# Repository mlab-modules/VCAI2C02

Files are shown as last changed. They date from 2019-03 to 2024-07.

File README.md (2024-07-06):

# VCAI2C02A

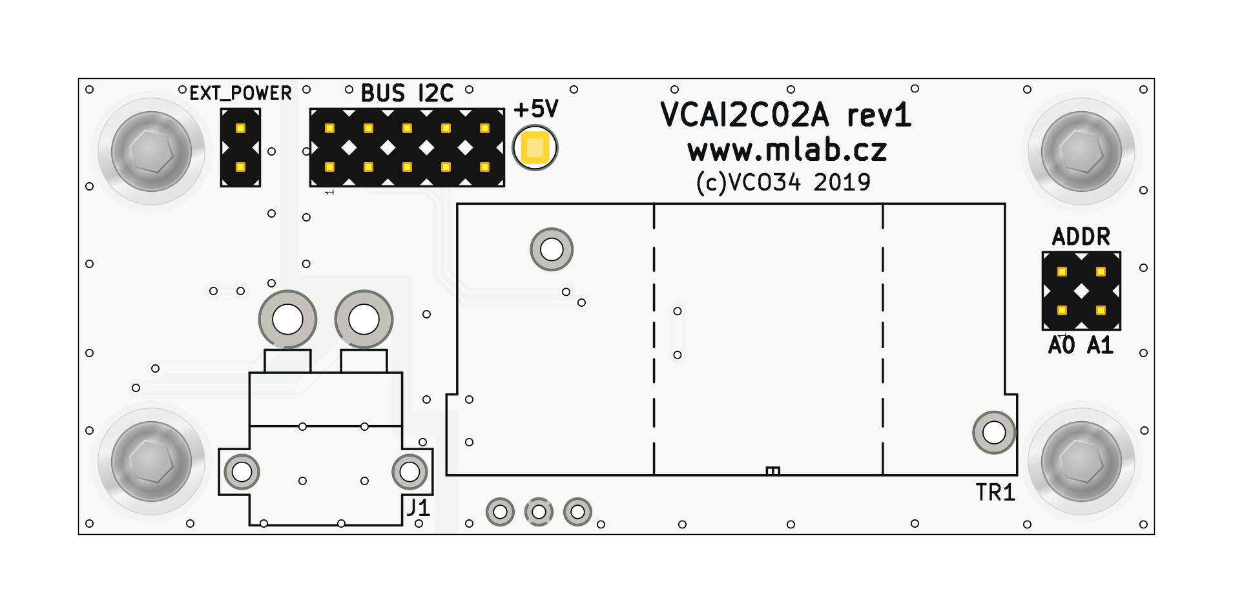
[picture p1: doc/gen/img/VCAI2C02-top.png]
VCAI2C02A

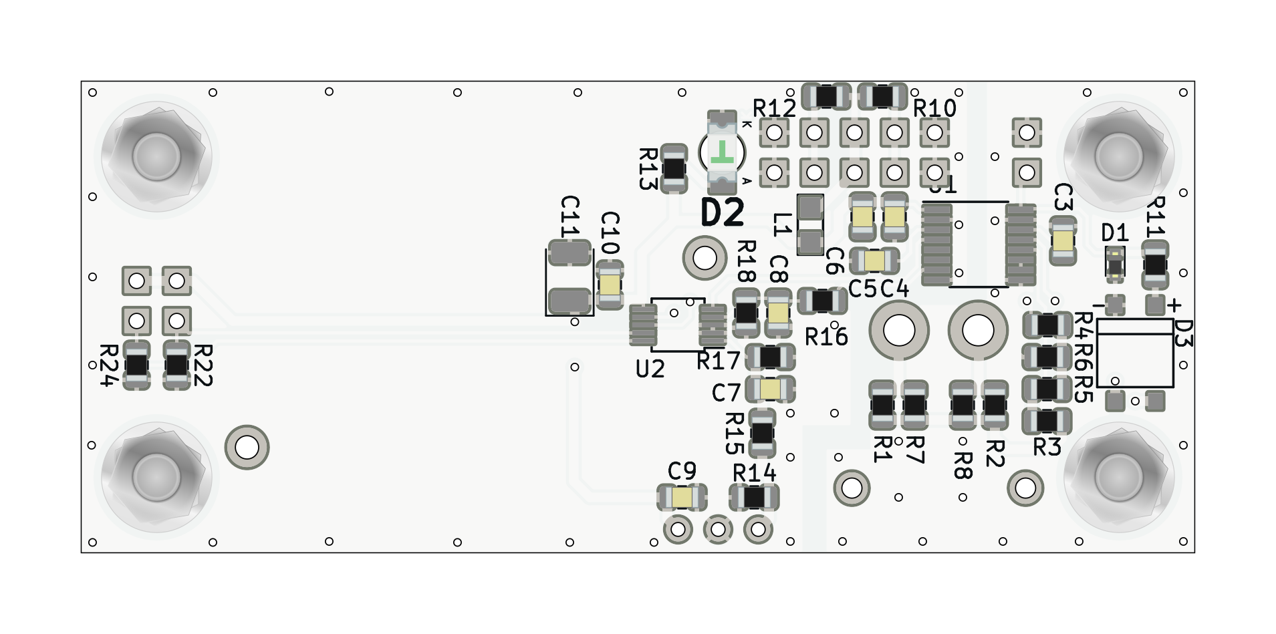
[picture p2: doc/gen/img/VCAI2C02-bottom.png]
VCAI2C02A bottom


## Overview

The VCAI2C02A is an I2C module designed for measuring current (0-50A) and voltage (0-50V) using a measuring transformer. It integrates multiple components to provide accurate and reliable measurements for various applications.

## Features

- **Current Measurement:** 0 to 50A
- **Voltage Measurement:** 0 to 50V
- **Interface:** I2C
- **Measurement Transformer:** Included
- **Connectors:** XT30PW-M and XT30PW-F
- **High Stability Isolated Error Amplifier:** ADuM3190
- **High-Resolution ADC:** MCP3423

## Components

### XT30PW Connectors

- **Item No:** XT30PW-M and XT30PW-F
- **Contact Resistance:** 0.80mΩ
- **Rated Voltage:** DC 500V
- **Rated Current:** 15A
- **Instantaneous Current:** 30A
- **Material:** Brass Gold Plated
- **Insulation Material:** PA, UL94 V0
- **Operating Temperature:** -20℃ to 120℃

### ADuM3190 Isolated Error Amplifier

- **Stability in isolated feedback applications**
- **Initial Accuracy:** 0.5%
- **Accuracy over Temperature Range:** 1%
- **Reference Voltage:** 1.225V
- **Bandwidth:** 400 kHz
- **Isolation Voltage:** 2.5 kV rms
- **Temperature Range:** -40°C to +125°C

### MCP3423 ADC

- **Resolution:** 18-bit
- **Interface:** I2C
- **Programmable Data Rate**
- **Internal Voltage Reference:** 2.048V

### Hall Effect Current Sensor (Tamura L01ZXXXS05 Series)

- **Type:** Open Loop
- **Mounting:** PCB
- **Nominal Current:** Up to 600A
- **Accuracy:** Excellent accuracy and linearity
- **Temperature Drift:** Low
- **Frequency Bandwidth:** Wide
- **No Insertion Loss**

## Applications

- **Linear Power Supplies**
- **Inverters**
- **Uninterruptible Power Supply (UPS)**
- **DOSA-compatible Modules**
- **Voltage Monitors**
- **Automotive and drone Systems**

## Additional Resources

For more detailed information, please refer to the datasheets of the components used in the VCAI2C02A module:

- [ADuM3190 Datasheet](https://www.analog.com/media/en/technical-documentation/data-sheets/ADuM3190.pdf)
- [MCP3423 Datasheet](https://www.microchip.com/wwwproducts/en/MCP3423)
- [XT30PW Connectors Specification](http://www.china-amass.com/)

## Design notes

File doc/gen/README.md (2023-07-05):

# PCB

Board size: 70.61x29.97 mm (2.78x1.18 inches)

- This is the size of the rectangle that contains the board
- Thickness: 1.6 mm (63 mils)
- Material: FR4
- Finish: HAL
- Layers: 2
- Copper thickness: 35 µm

Solder mask: TOP / BOTTOM

- Color: Green

Silk screen: TOP / BOTTOM

- Color: White

# Important sizes

Clearance: 0.2 mm (8 mils)

Track width: 0.2 mm (8 mils)

- By design rules: 0.2 mm (8 mils)

Drill: 0.5 mm (20 mils)

- Vias: 0.5 mm (20 mils) [Design: 0.3 mm (12 mils)]
- Pads: 0.9 mm (35 mils)
- The above values are real drill sizes, they add 0.1 mm (4 mils) to plated holes (PTH)

Via: 0.8/0.4 mm (31/16 mils)

- By design rules: 0.8/0.2 mm (31/8 mils)
- Micro via: yes [0.2/0.1 mm (8/4 mils)]
- Buried/blind via: yes
- Total: 54 (thru: 54 buried/blind: 0 micro: 0)

Outer Annular Ring: 0.15 mm (6 mils)

- By design rules: 0.26 mm (10 mils)

Eurocircuits class: 4B
- Using min drill 0.5 mm for an OAR of 0.15 mm

# General stats

Components count: (SMD/THT)

- Top: 0/9 (THT)
- Bottom: 32/2 (SMD + THT)

Defined tracks:

- 0.2 mm (8 mils)
- 0.4 mm (16 mils)
- 0.6 mm (24 mils)
- 0.8 mm (31 mils)
- 1.0 mm (39 mils)

Used tracks:

- 0.2 mm (8 mils) (187) defined: yes
- 0.4 mm (16 mils) (15) defined: yes
- 0.6 mm (24 mils) (70) defined: yes

Defined vias:

Used vias:

- 0.8/0.4 mm (31/16 mils) (Count: 54, Aspect: 2.0 A) defined: no

Holes (excluding vias):

- 0.8 mm (31 mils) (3)
- 0.89 mm (35 mils) (16)
- 1.2 mm (47 mils) (2)
- 1.4 mm (55 mils) (2)
- 1.9 mm (75 mils) (2)
- 2.7 mm (106 mils) (1)
- 3.0 mm (118 mils) (4)

Oval holes:

Drill tools (including vias and computing adjusts and rounding):

- 0.5 mm (20 mils) (54)
- 0.9 mm (35 mils) (3)
- 1.0 mm (39 mils) (16)
- 1.3 mm (51 mils) (2)
- 1.5 mm (59 mils) (2)
- 2.0 mm (79 mils) (2)
- 2.7 mm (106 mils) (1)
- 3.1 mm (122 mils) (4)

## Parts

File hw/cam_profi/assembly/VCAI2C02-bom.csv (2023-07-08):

Component | Description | Part | References | Value | Footprint | Quantity Per PCB | Datasheet | ust_id | mfpn
1 |  | C-Device | C7C8 | 10n | C_0805_2012Metric | 2 |  | 5c70984712875079b91f8b49
2 |  | C-Device | C4C9C10 | 100n | C_0805_2012Metric | 3 |  | 5c70984712875079b91f8b4c
3 |  | C-Device | C3C5C6 | 1u | C_0805_2012Metric | 3 |  | 5c70984812875079b91f8bc2
4 |  | C-Device | C11 | 10uF | CP_EIA-3528-21_Kemet-B | 1 |  | 5c70984412875079b91f8865
5 |  | LED-Device | D2 | +5V -Green | LED_1206 | 1 |  | 5c70984412875079b91f8895
6 |  | D_Bridge_+-AA-Device | D3 | CDBHM260L-HF | MSB-2 | 1 |  | 5cb5829a1287500e61c99661
7 |  | D_Zener-Device | D1 | MM5Z10VT1G | D_SOD-523 | 1 |  | 5cb5832e1287500e61c99679
8 |  | Conn_02x02_Odd_Even-Connector_Generic | J6 | ADDR | Straight_2x02 | 1
9 |  | Conn_02x05_Odd_Even-Connector_Generic | J4 | BUS I2C | Straight_2x05 | 1
10 |  | Conn_01x02-Connector_Generic | J5 | EXT_POWER | Straight_2x01 | 1
11 |  | Conn_01x02-Connector_Generic | J1 | IN 50V(max) | XT30PW-M | 1 |  | 5c70984812875079b91f8ba8
12 |  | L-Device | L1 | BLM21PG300SN1D | BLM21PG_3Amp | 1 |  | 5c70984412875079b91f87fd
13 |  | R-Device | R13 | 330R | R_0805_2012Metric | 1 |  | 5c70984512875079b91f8984
14 |  | R-Device | R5 | 1k5 | R_0805_2012Metric | 1 |  | 5c70984512875079b91f898e
15 |  | R-Device | R11 | 3k9 | R_0805_2012Metric | 1 |  | 5c70984612875079b91f8994
16 |  | R-Device | R10R12R14R22R24 | 10k | R_0805_2012Metric | 5 |  | 5c70984612875079b91f899f
17 |  | R-Device | R6 | 16k9 | R_0805_2012Metric | 1 |  | 5cb83a291287500e61c99759
18 |  | R-Device | R17R18 | 33k | R_0805_2012Metric | 2 |  | 5c70984712875079b91f8a8a
19 |  | R-Device | R4 | 40k2 | R_0805_2012Metric | 1 |  | 5cb839571287500e61c9974a
20 |  | R-Device | R3 | 50k | R_0805_2012Metric | 1 |  | 5cb585391287500e61c9968c
21 |  | R-Device | R15R16 | 180k | R_0805_2012Metric | 2 |  | 5c70984712875079b91f8a9c
22 |  | R-Device | R1R2R7R8 | 1M | R_0805_2012Metric | 4 |  | 5c70984712875079b91f8aaa
23 |  | L01ZxxxS05 | TR1 | L01ZxxxS05 | L01ZxxxS05 | 1 |  | 5cb581511287500e61c99631 | L01Z100S05
24 |  | ADuM3190 | U1 | ADuM3190ARQZ | QSOP-16_3.9x4.9mm_P0.635mm | 1 |  | 5cb589091287500e61c996a0 | ADuM3190ARQZ
25 |  | MCP3423-Analog_ADC | U2 | MCP3423-E/UN | MSOP-10_3x3mm_P0.5mm | 1 | http://ww1.microchip.com/downloads/en/DeviceDoc/22088c.pdf | 5cb589b51287500e61c996bf | MCP3423-E/UN

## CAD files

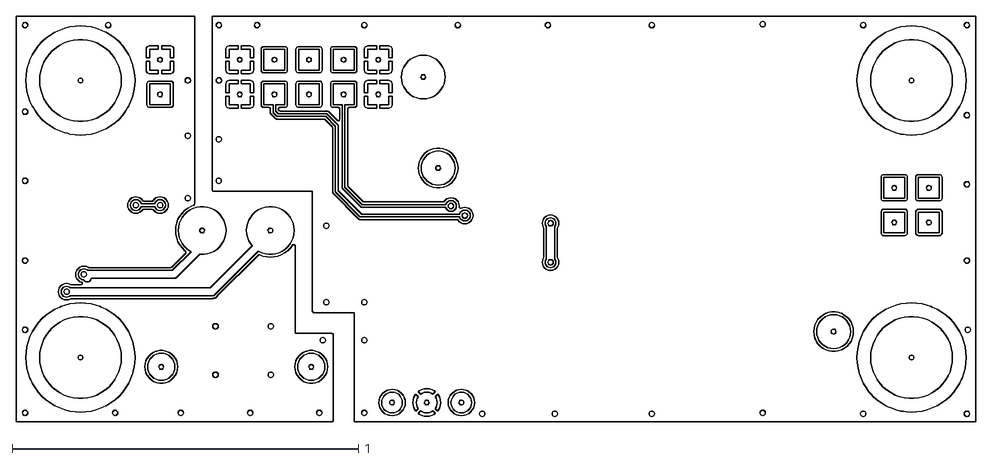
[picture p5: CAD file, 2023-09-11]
doc/gen/dxf/VCAI2C02-F_Cu.dxf
2.77 x 1.17

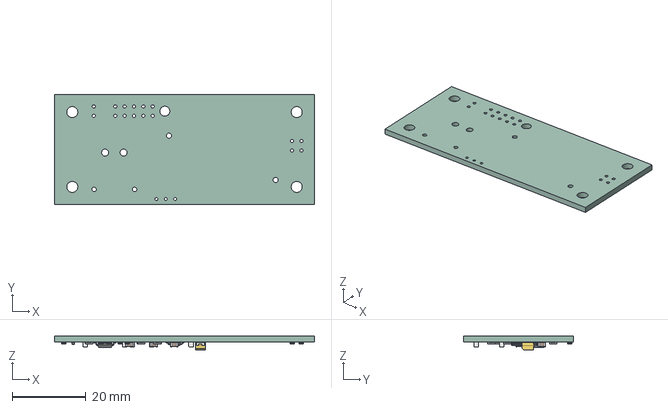
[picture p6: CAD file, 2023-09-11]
doc/gen/VCAI2C02.step
70.6 x 30.0 x 3.75 mm
tmpodnhxvpo PCB

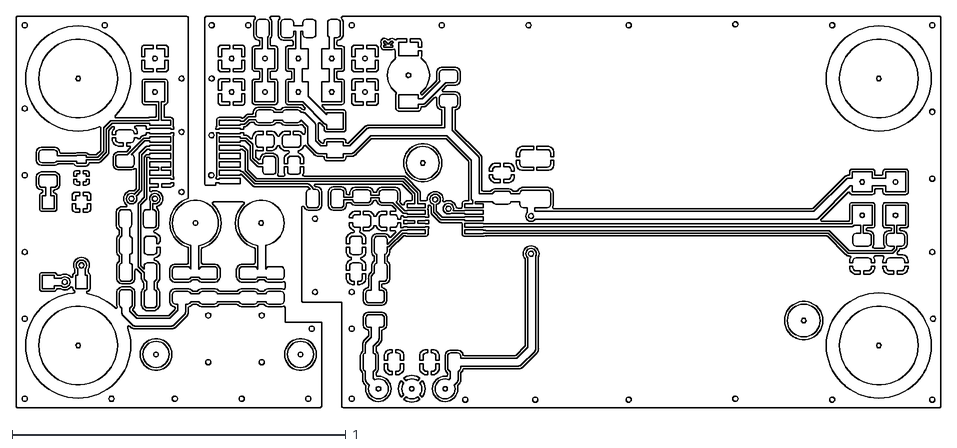
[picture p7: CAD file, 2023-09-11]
doc/gen/dxf/VCAI2C02-B_Cu.dxf
2.77 x 1.17

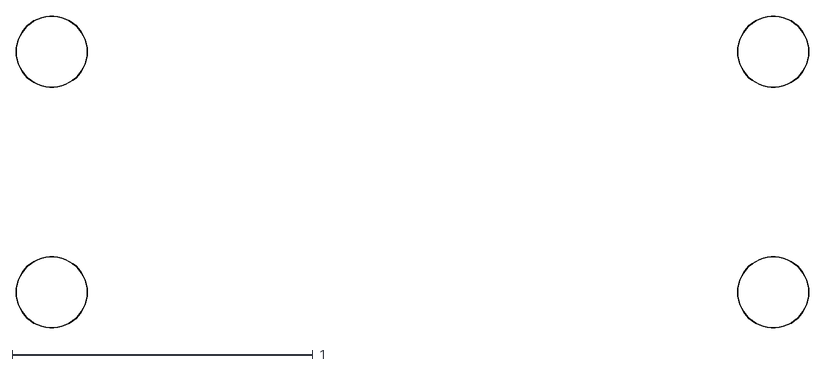
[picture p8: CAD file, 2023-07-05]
doc/gen/dxf/VCAI2C02-B_Adhesive.dxf
2.64 x 1.04

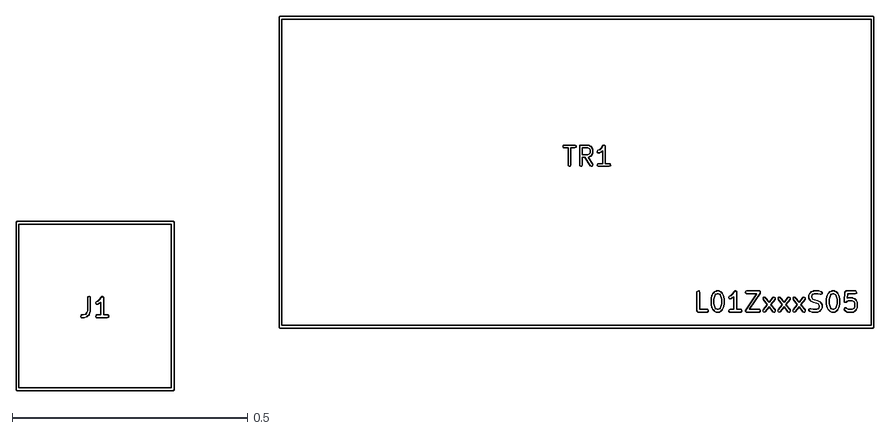
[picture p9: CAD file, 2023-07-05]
doc/gen/dxf/VCAI2C02-F_Fab.dxf
1.83 x 0.796

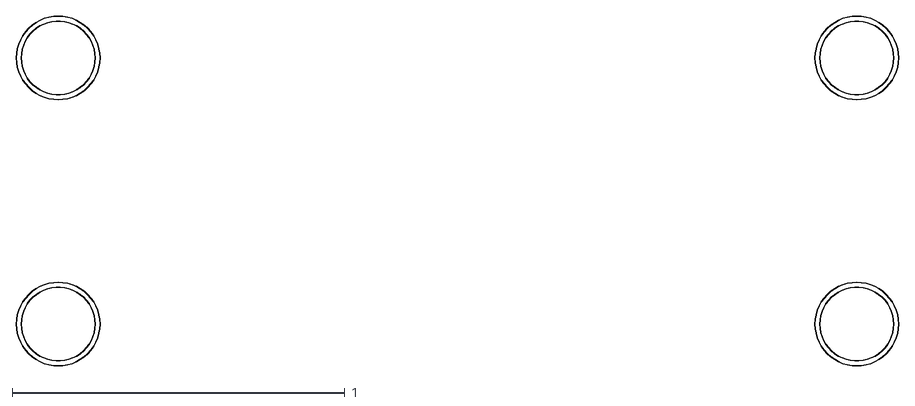
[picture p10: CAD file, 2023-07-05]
doc/gen/dxf/VCAI2C02-User_Comments.dxf
2.65 x 1.05

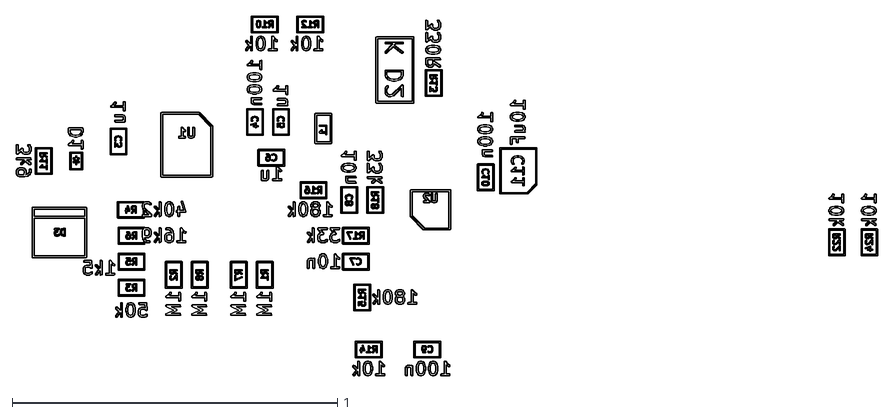
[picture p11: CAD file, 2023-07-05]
doc/gen/dxf/VCAI2C02-B_Fab.dxf
2.65 x 1.11

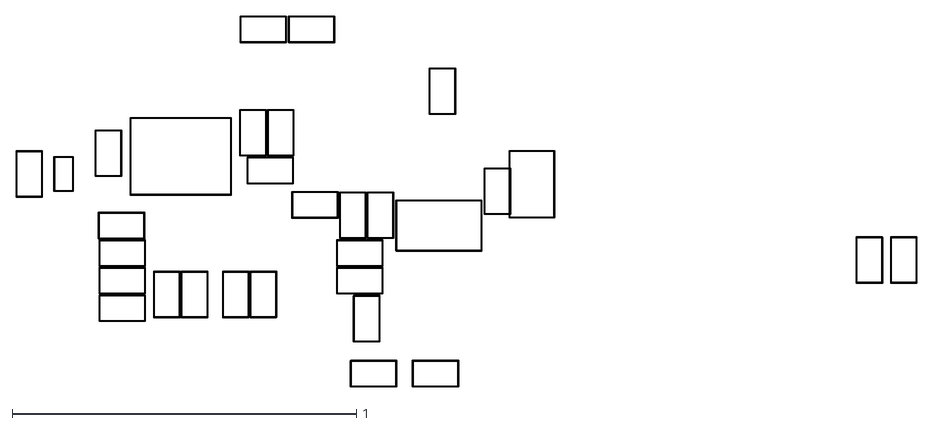
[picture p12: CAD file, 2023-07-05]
doc/gen/dxf/VCAI2C02-B_Courtyard.dxf
2.62 x 1.08

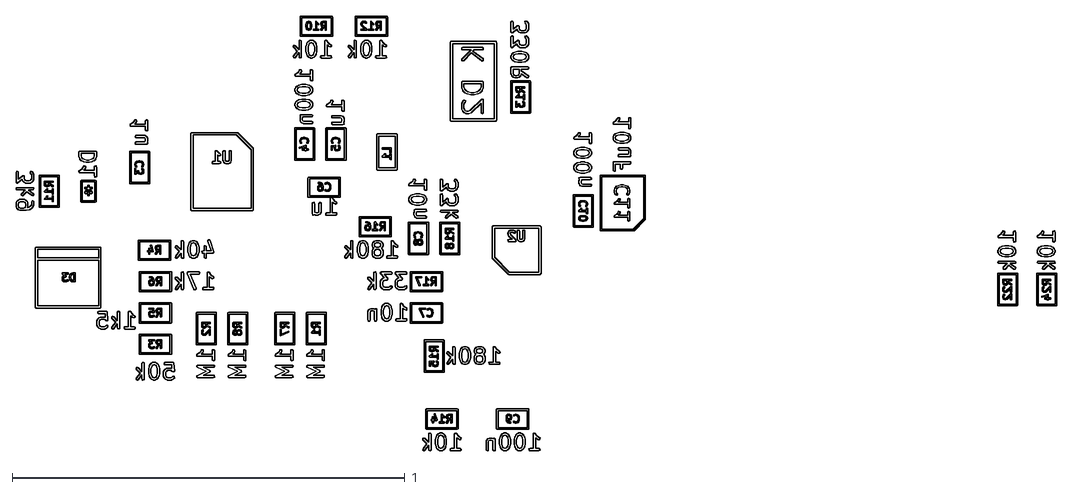
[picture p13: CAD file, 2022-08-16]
doc/gen/dxf/VCAI2C02A-B_Fab.dxf
2.65 x 1.11

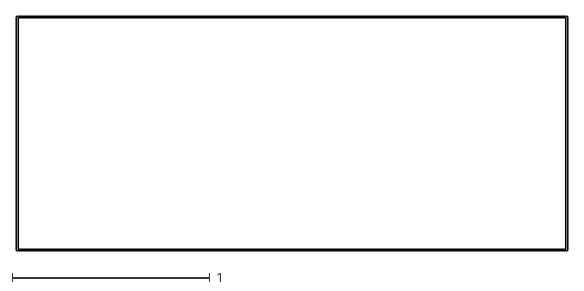
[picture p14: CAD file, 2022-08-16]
doc/gen/dxf/VCAI2C02-Edge_Cuts.dxf
2.79 x 1.19

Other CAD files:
doc/gen/dxf/VCAI2C02-F_Courtyard.dxf
doc/gen/dxf/VCAI2C02-User_Drawings.dxf
doc/gen/dxf/VCAI2C02-Margin.dxf
doc/gen/dxf/VCAI2C02-User_Eco1.dxf
doc/gen/dxf/VCAI2C02-User_Eco2.dxf
doc/gen/dxf/VCAI2C02-B_Mask.dxf
doc/gen/dxf/VCAI2C02-B_Paste.dxf
doc/gen/dxf/VCAI2C02-B_Silkscreen.dxf
doc/gen/dxf/VCAI2C02-F_Mask.dxf
doc/gen/dxf/VCAI2C02-F_Paste.dxf
doc/gen/dxf/VCAI2C02-F_Silkscreen.dxf

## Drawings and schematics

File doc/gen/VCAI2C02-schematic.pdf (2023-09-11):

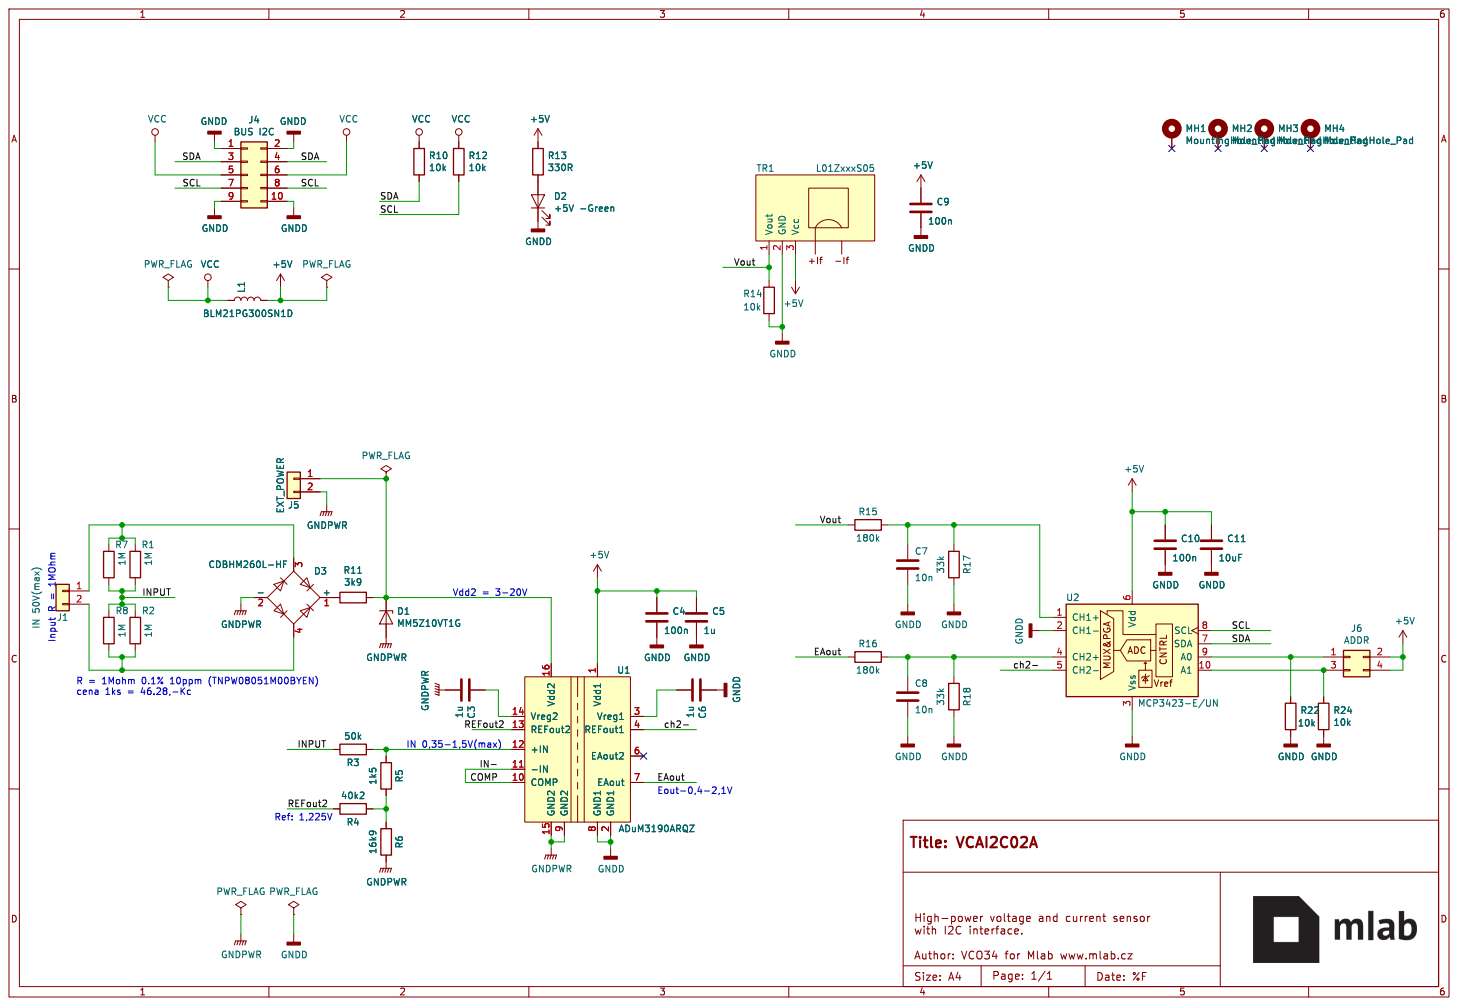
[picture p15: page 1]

6 SDA 7 SCL 8 A0 9 U2 MCP3423-E/UN GNDD

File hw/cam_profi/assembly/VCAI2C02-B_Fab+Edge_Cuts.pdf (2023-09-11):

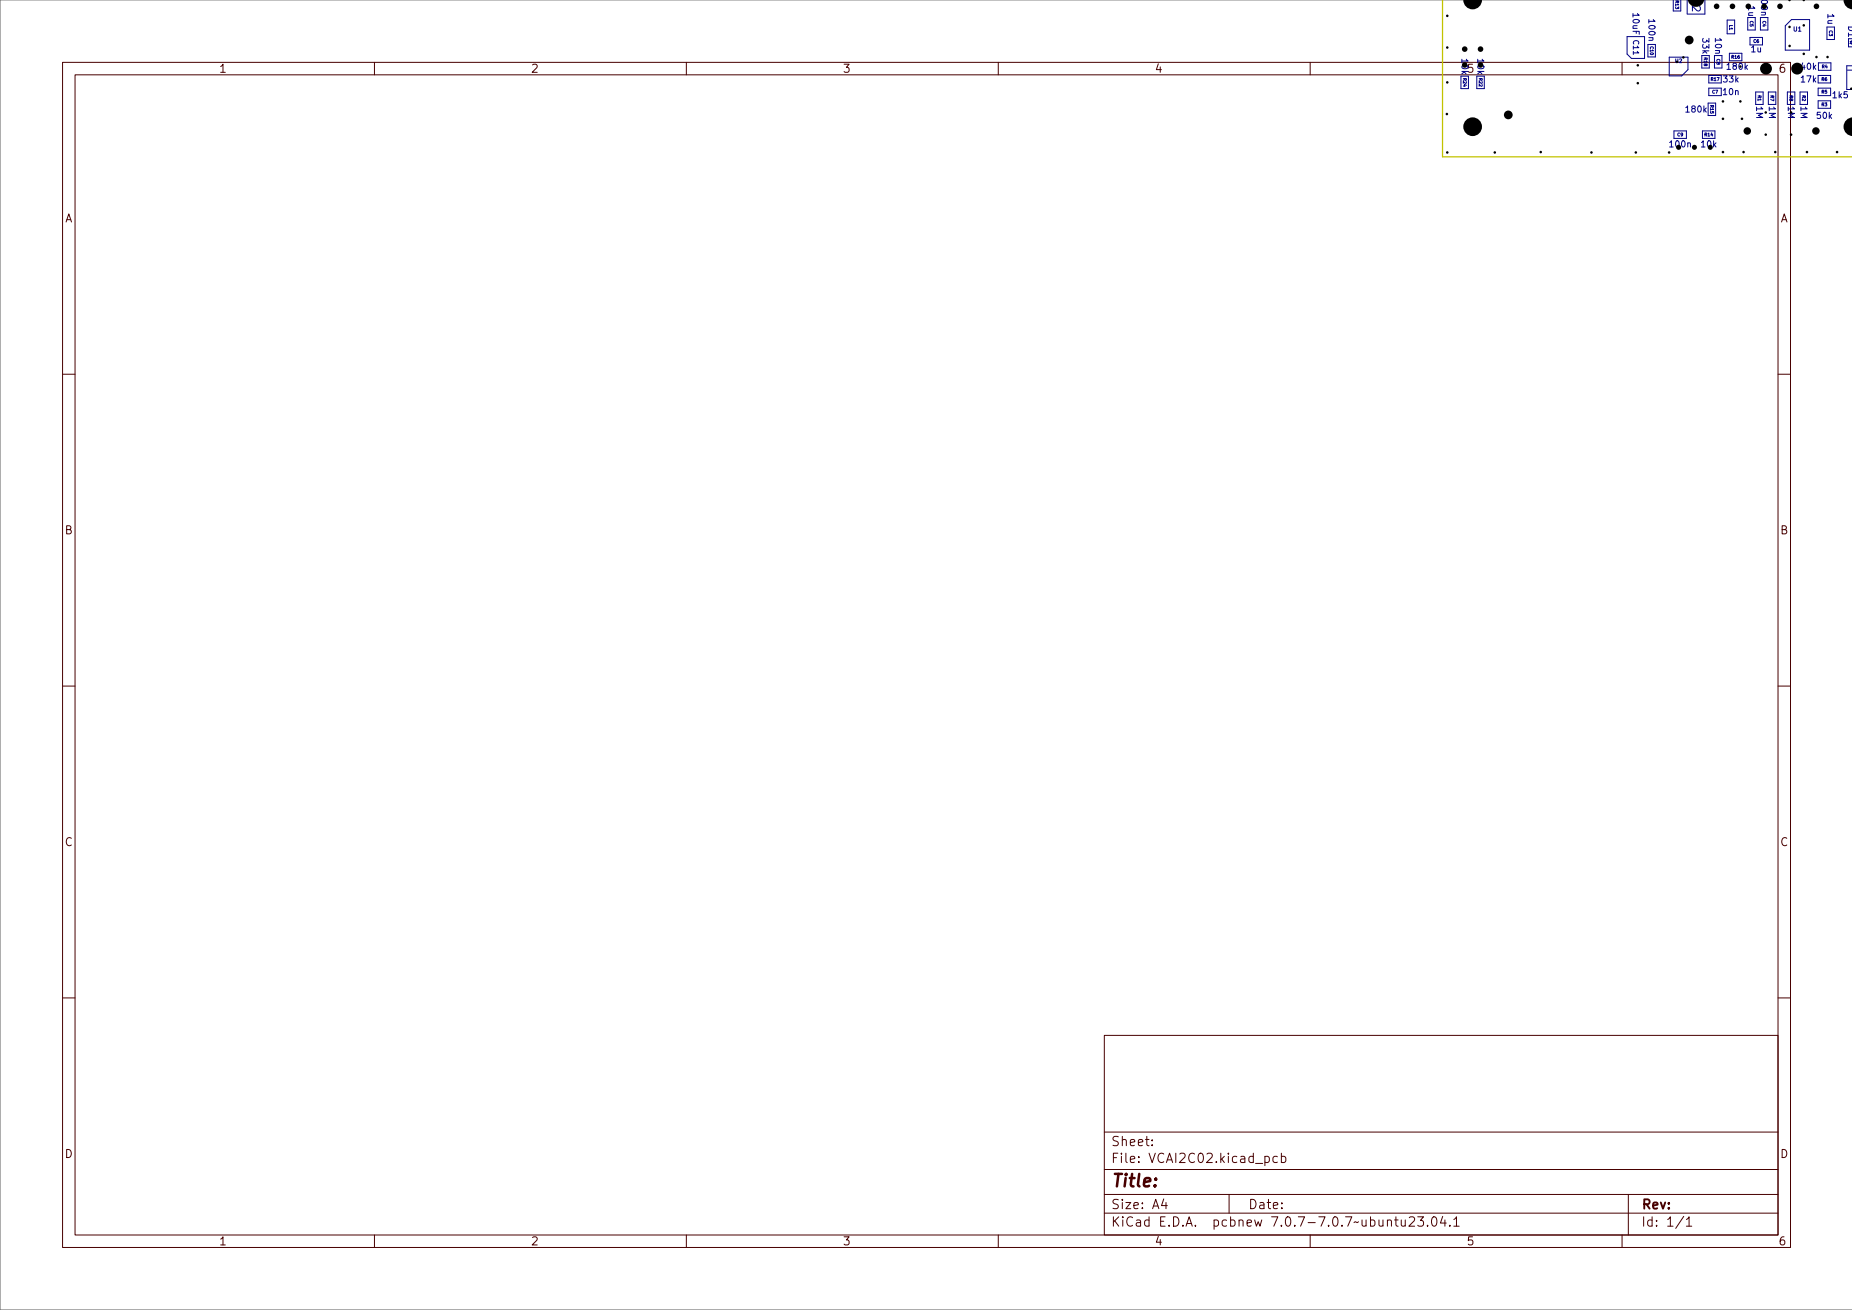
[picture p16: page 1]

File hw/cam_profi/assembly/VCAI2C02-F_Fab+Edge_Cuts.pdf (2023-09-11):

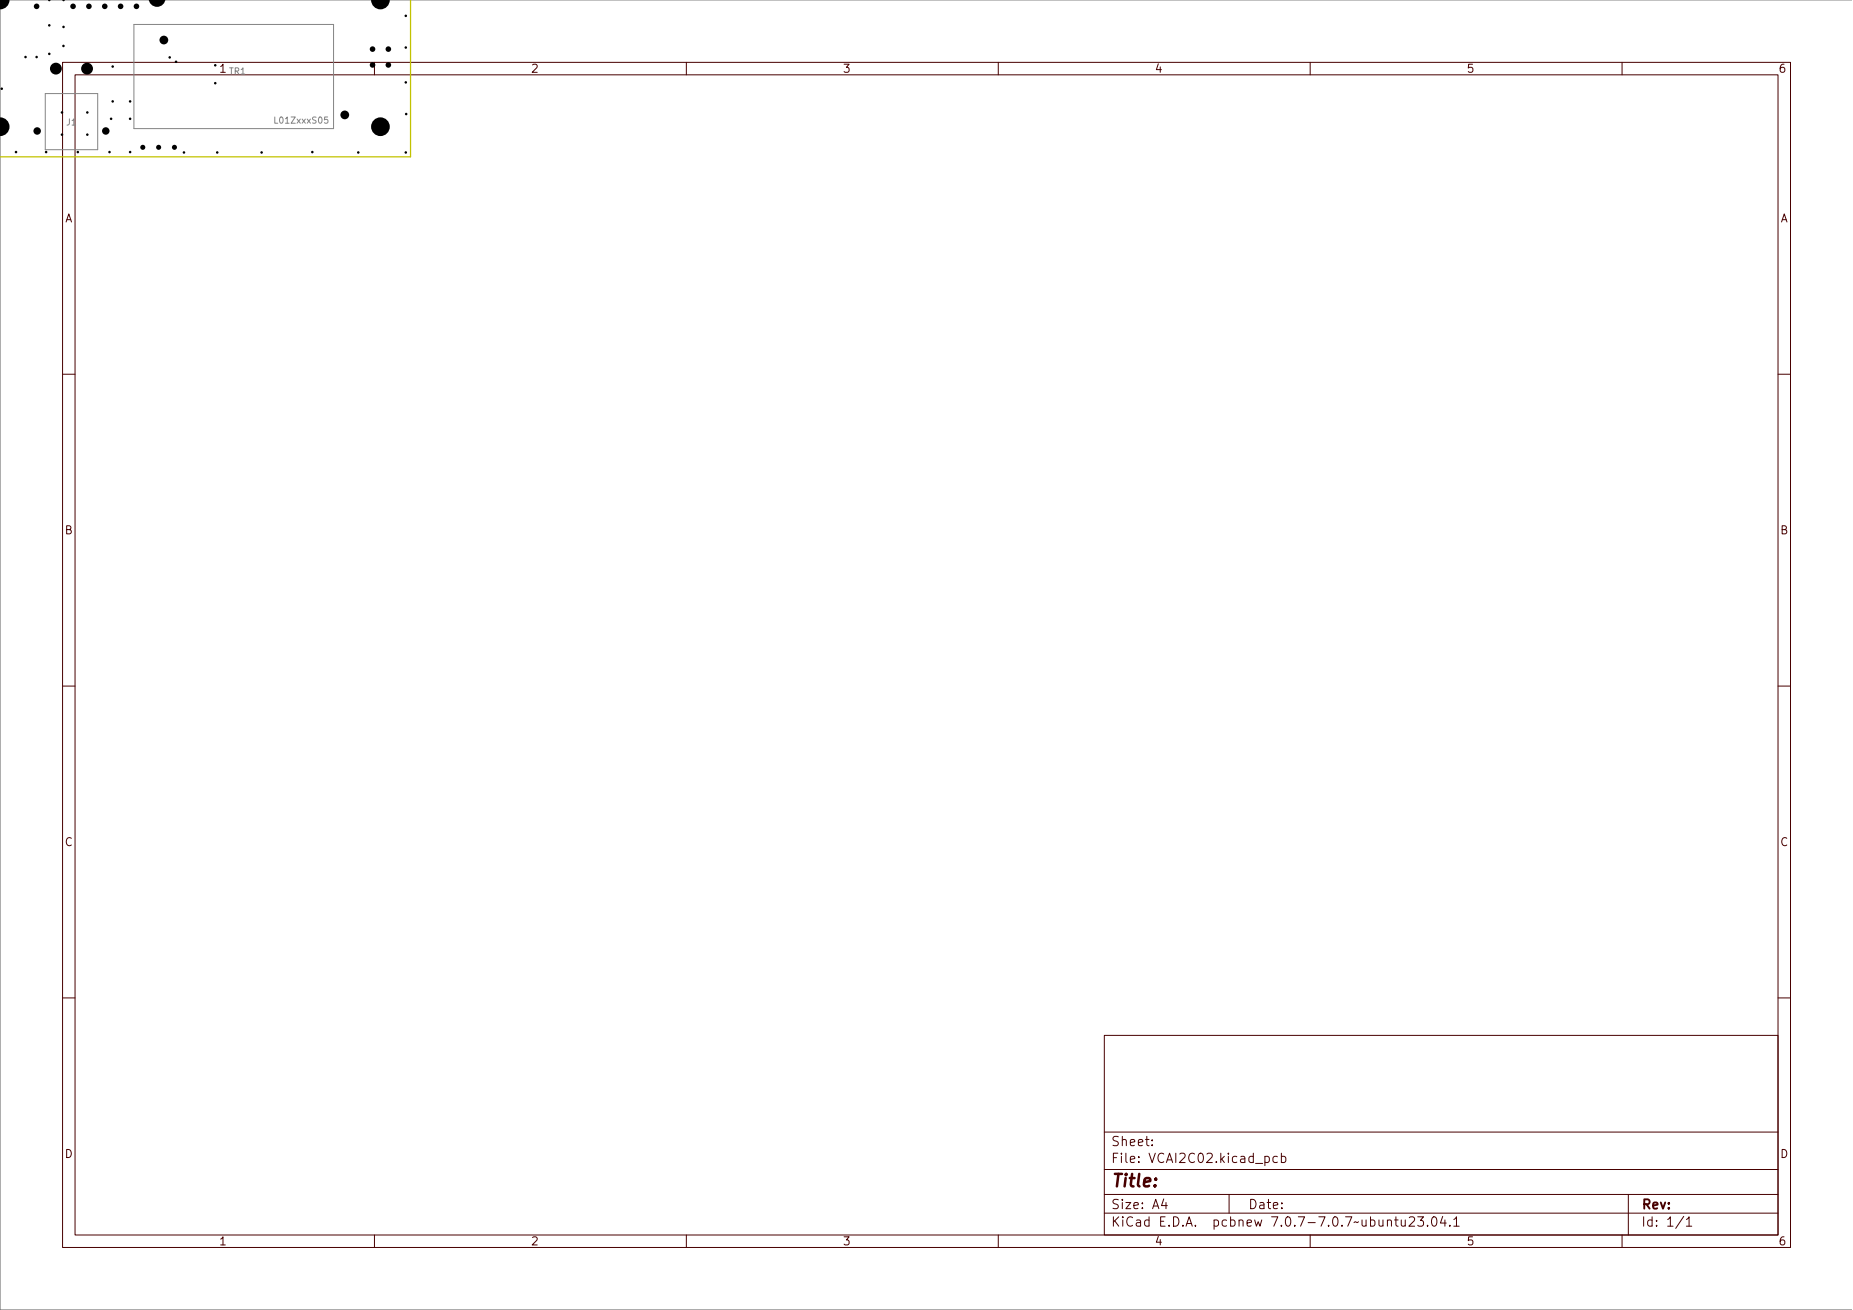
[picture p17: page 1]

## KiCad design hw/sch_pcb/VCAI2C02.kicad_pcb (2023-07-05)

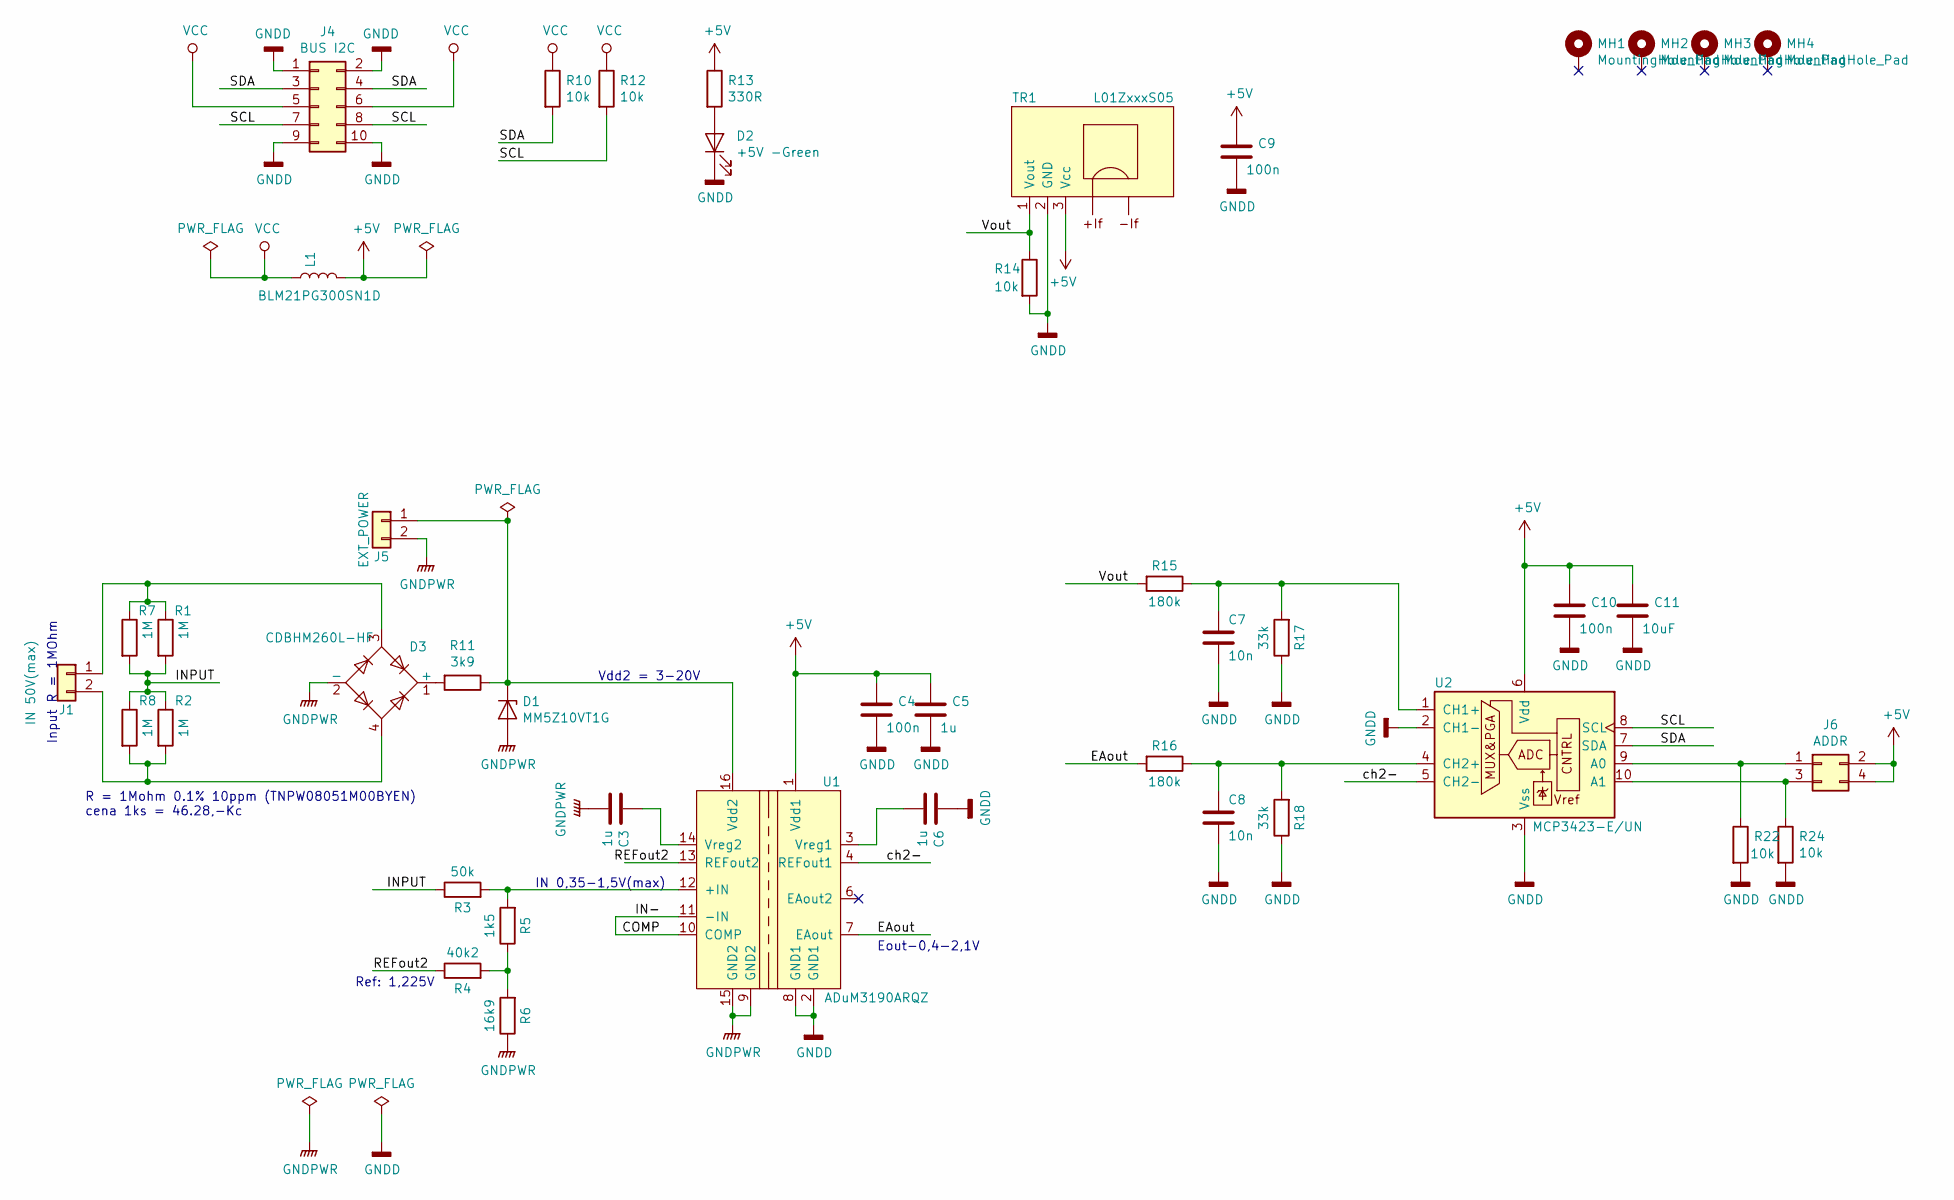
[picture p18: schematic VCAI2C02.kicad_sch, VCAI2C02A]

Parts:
C3, C5, C6: 1u; C_0805_2012Metric
C4, C9, C10: 100n; C_0805_2012Metric
C7, C8: 10n; C_0805_2012Metric
C11: 10uF; CP_EIA-3528-21_Kemet-B
D1: MM5Z10VT1G; D_SOD-523
D2: +5V -Green; LED_1206
D3: CDBHM260L-HF; MSB-2
J1: IN 50V(max); XT30PW-M
J4: BUS I2C; Straight_2x05
J5: EXT_POWER; Straight_2x01
J6: ADDR; Straight_2x02
L1: BLM21PG300SN1D; BLM21PG_3Amp
MH1, MH2, MH3, MH4: MountingHole_Pad; MountingHole_3mm
R1, R2, R7, R8: 1M; R_0805_2012Metric
R3: 50k; R_0805_2012Metric
R4: 40k2; R_0805_2012Metric
R5: 1k5; R_0805_2012Metric
R6: 16k9; R_0805_2012Metric
R10, R12, R14, R22, R24: 10k; R_0805_2012Metric
R11: 3k9; R_0805_2012Metric
R13: 330R; R_0805_2012Metric
R15, R16: 180k; R_0805_2012Metric
R17, R18: 33k; R_0805_2012Metric
TR1: L01ZxxxS05
U1: ADuM3190ARQZ; QSOP-16_3.9x4.9mm_P0.635mm
U2: MCP3423-E/UN; MSOP-10_3x3mm_P0.5mm

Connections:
+5V: C4.1, C5.1, C9.1, C10.1, C11.1, J6.2, J6.4, L1.2, R13.1, TR1.3 (Vcc), U1.1 (Vdd1), U2.6 (Vdd)
/COMP: U1.10 (COMP), U1.11 (-IN)
/EAout: R16.2, U1.7 (EAout)
/INPUT: R1.2, R2.1, R3.1, R7.2, R8.1
/REFout2: R4.1, U1.13 (REFout2)
/SCL: J4.7, J4.8, R12.2, U2.8 (SCL)
/SDA: J4.3, J4.4, R10.2, U2.7 (SDA)
/Vout: R14.1, R15.2, TR1.1 (Vout)
/ch2-: U1.4 (REFout1), U2.5 (CH2-)
GNDD: C4.2, C5.2, C6.1, C7.2, C8.2, C9.2, C10.2, C11.2, D2.1 (K), J4.1, J4.2, J4.9, J4.10, R14.2, R17.1, R18.1, R22.2, R24.2, TR1.2 (GND), U1.2 (GND1), U1.8 (GND1), U2.2 (CH1-), U2.3 (Vss)
GNDPWR: C3.2, D1.2 (A), D3.2 (-), J5.2, R6.1, U1.9 (GND2), U1.15 (GND2)
unnamed: C3.1, U1.14 (Vreg2)
unnamed: C6.2, U1.3 (Vreg1)
unnamed: C7.1, R15.1, R17.2, U2.1 (CH1+)
unnamed: C8.1, R16.1, R18.2, U2.4 (CH2+)
unnamed: D1.1 (K), J5.1, R11.1, U1.16 (Vdd2)
unnamed: D2.2 (A), R13.2
unnamed: D3.1 (+), R11.2
unnamed: D3.3, J1.1, R1.1, R7.1
unnamed: D3.4, J1.2, R2.2, R8.2
unnamed: J6.1, R22.1, U2.9 (A0)
unnamed: J6.3, R24.1, U2.10 (A1)
unnamed: R3.2, R5.2, U1.12 (+IN)
unnamed: R4.2, R5.1, R6.2
VCC: J4.5, J4.6, L1.1, R10.1, R12.1

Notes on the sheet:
Vdd2 = 3-20V
IN 0,35-1,5V(max)
Input R = 1MOhm
R = 1Mohm 0.1% 10ppm (TNPW08051M00BYEN) cena 1ks = 46.28,-Kc
Eout-0,4-2,1V
Ref: 1,225V

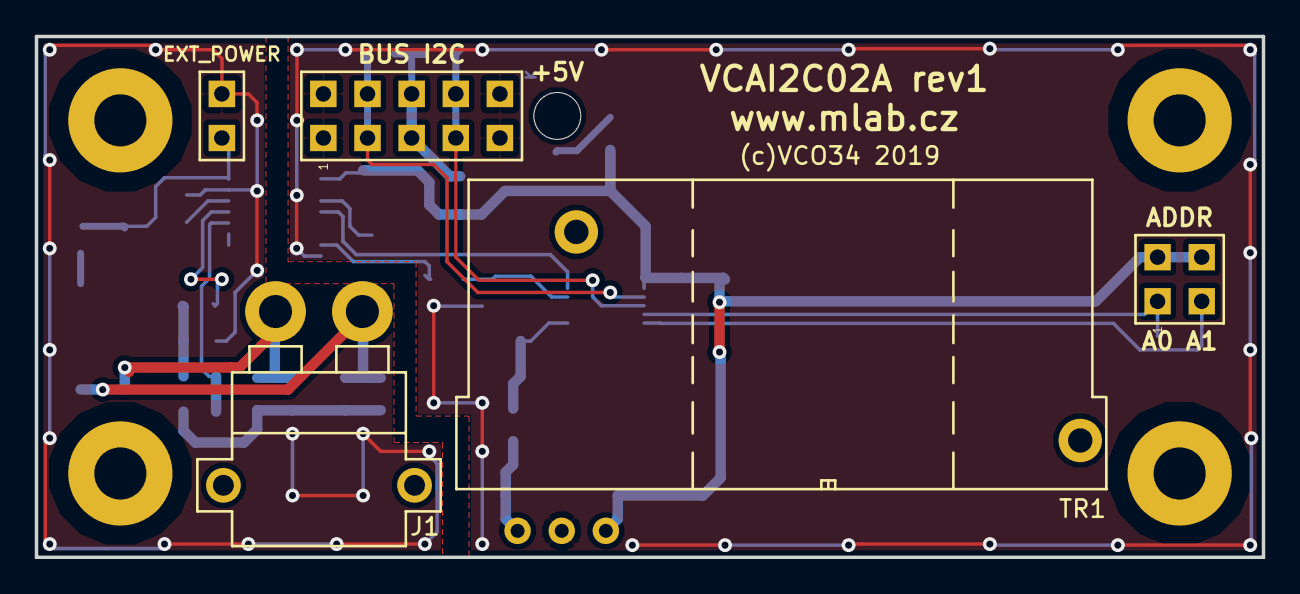
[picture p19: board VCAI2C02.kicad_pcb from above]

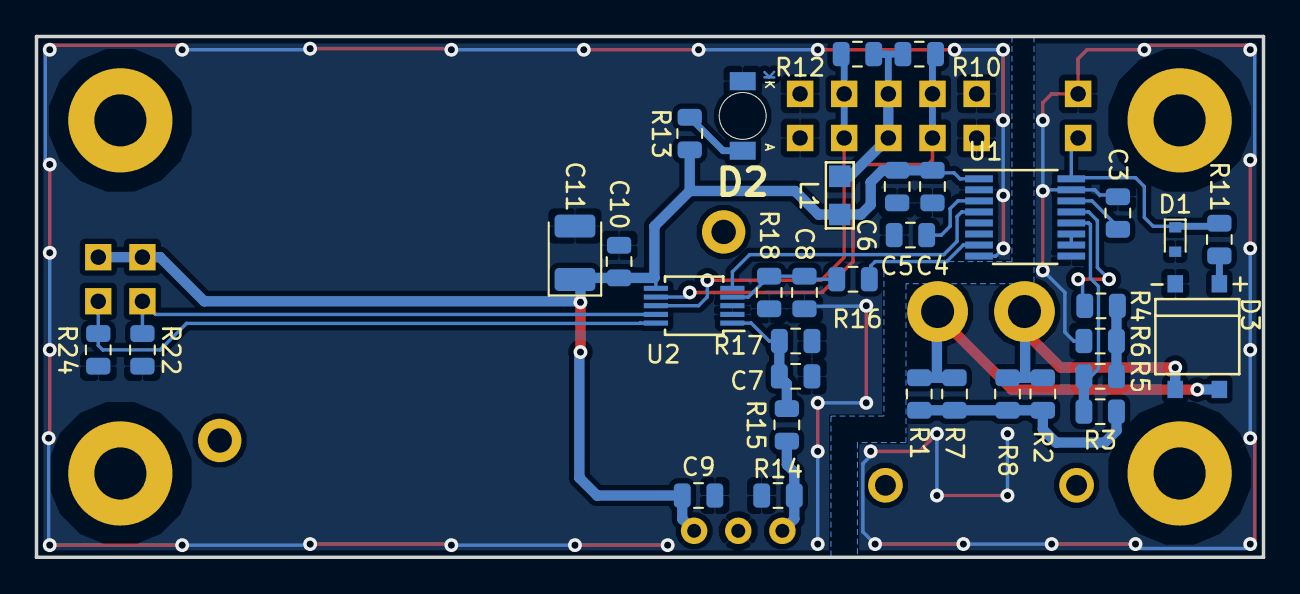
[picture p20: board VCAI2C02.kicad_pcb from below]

Board: 2 copper layers, 70.6 x 30.0 mm, 43 parts (34 on the bottom side), 25 nets.

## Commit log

2019-03-14 [MLABweb] Documentaion edits; VCAI2C02A
    [VCAI2C02A.kicad_pcb, VCAI2C02A.sch]
2019-03-14 update schematic v1.0
    [VCAI2C02A.kicad_pcb, VCAI2C02A.sch]
2019-03-15 update schematic by comment kaklik issue #5
    [VCAI2C02A.sch]
2019-03-15 oprava chyb, přidání compenzation network
    [VCAI2C02A.sch]
2019-03-20 add simulation data http://www.falstad.com/circuit/circuitjs.html
2019-03-20 edit schematic by simulation
    [VCAI2C02A.sch]
2019-03-28 DPS rev 1
    [VCAI2C02A.kicad_pcb, VCAI2C02A.sch]
2019-03-29 - doplněné přesné názvy součástek MCP a ADU integrovaného obvodu - doplněno MFPN pro měřící transformátor (100A verze) - změněny pouzdra R a C na 0805
    [VCAI2C02A.kicad_pcb, VCAI2C02A.sch]
2019-04-02 Generování bom.
2019-04-08 Generování výrobních dat
    [VCAI2C02A-B.Cu.gbr, VCAI2C02A-B.Mask.gbr, VCAI2C02A-Edge.Cuts.gbr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]
2019-04-16 Doplneno UST_ID do schema
    [VCAI2C02A.sch]
2019-04-18 correct resistor value R4 to 40.2k, R6 to 16.9k
    [VCAI2C02A.sch]
2019-04-24 update F.Fab and B.Fab
    [VCAI2C02A.kicad_pcb]
2019-05-24 Edit power module
    [VCAI2C02A.sch]
2022-08-16 Update to kicad 6.0 Update titleblocks Add actions scripts.
    [VCAI2C02A.kicad_sch]
2022-08-16 Update actions products
    [VCAI2C02A-B_Adhesive.dxf, VCAI2C02A-B_Courtyard.dxf, VCAI2C02A-B_Cu.dxf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]
2023-07-05 automated commit; rename source files to new naming convence
    [VCAI2C02A.kicad_pcb, VCAI2C02A.kicad_sch]
2023-07-05 update kicad
    [VCAI2C02.kicad_pcb, VCAI2C02.kicad_sch, VCAI2C02A.sch]

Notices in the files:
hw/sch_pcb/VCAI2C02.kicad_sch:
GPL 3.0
